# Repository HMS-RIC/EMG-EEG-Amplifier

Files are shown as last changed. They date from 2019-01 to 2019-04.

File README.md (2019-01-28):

# EMG/EEG-Amplifier
3 Channel instrumentation amplifier circuit using AD8221. 

**EMG:** 1 channel, fully differential. 3.2 Hz highpass and 100x gain.   
**EEG:** 2 channels use a common reference. 1.1 Hz highpass and 100x gain.  

Gain is set using a single 499 Ohm resistor per channel. 
Input bandwidth is set by RC network.

Black wire: GND  
Red wire: +5V  
White wire: -5V  
Blue wires (3): Outputs  

.asc file can be opened with LTspice to run the circuit simulation and plot frequency response and transient analysis

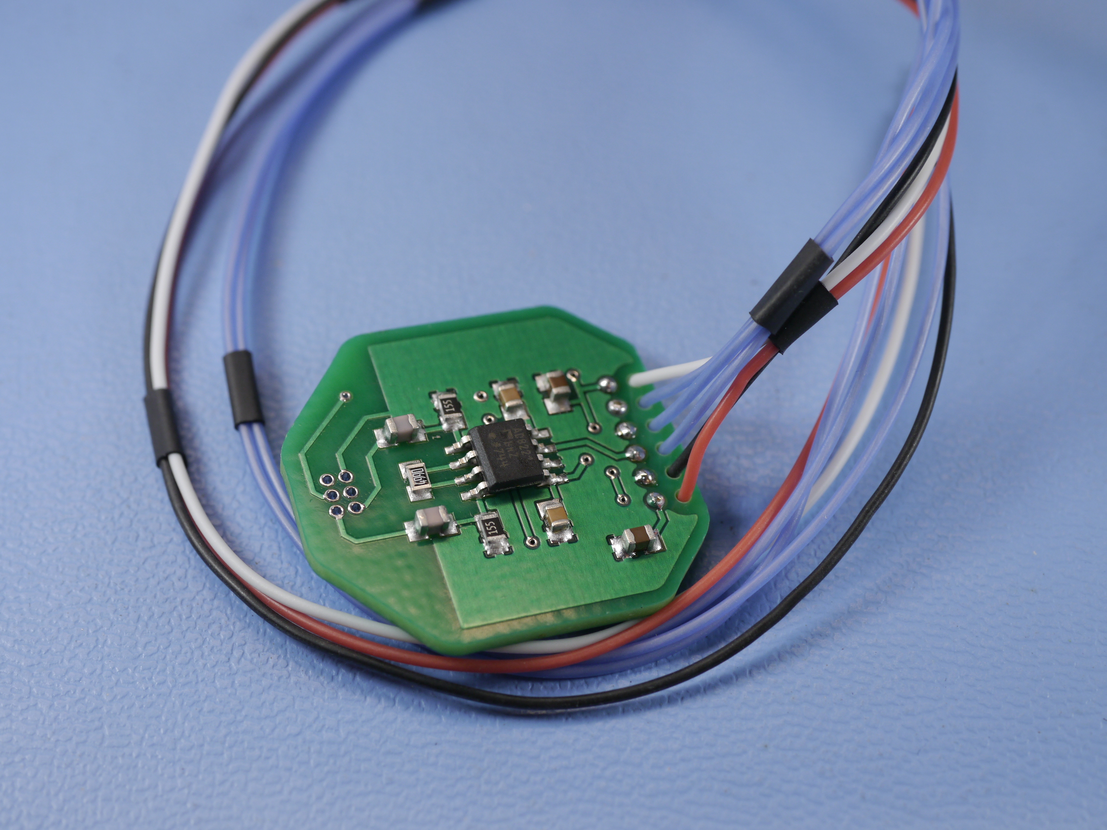
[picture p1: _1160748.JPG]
EMG/EEG Amplifier board


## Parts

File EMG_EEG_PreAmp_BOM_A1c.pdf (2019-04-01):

### Head-mounted EMG and EEG Preamplifier

(Alpha 1c, 2018)

Name | Value | Package | Description | Part Number
C1, C2 | .033 uF | 0805 | Input LP filter (diff channel)
C7, C8, C11, C12 | .1 uF | 0805 | Input LP filter (common channels)
C3, C5, C9, C10, C13, C14 | .1 uF | 0805 | Supply bypass caps
C4, C6 | 10 uF | 0805 | Supply bypass caps
RG1, RG2, RG3 | 499 | 0805 | Gain resistor
R1-R6 | 1.5M | 0805 | LP filter resistor
IC1-IC3 | SOIC8 | Instrumentation amplifier | AD8221

### HP Filter

Capacitors should be low leakage e.g. film
EMG: 1.5M and .01 uF (10.6 Hz cutoff) EEG: 1.5M and .22uF (.48 Hz cutoff)

### Version History:

Alpha 1a (Fabbed 2018)
Alpha 1b (Fabbed 2018)
1. Enlarged holes for millmax connector
2. Realized there is an error. IC3 was not connected to V-

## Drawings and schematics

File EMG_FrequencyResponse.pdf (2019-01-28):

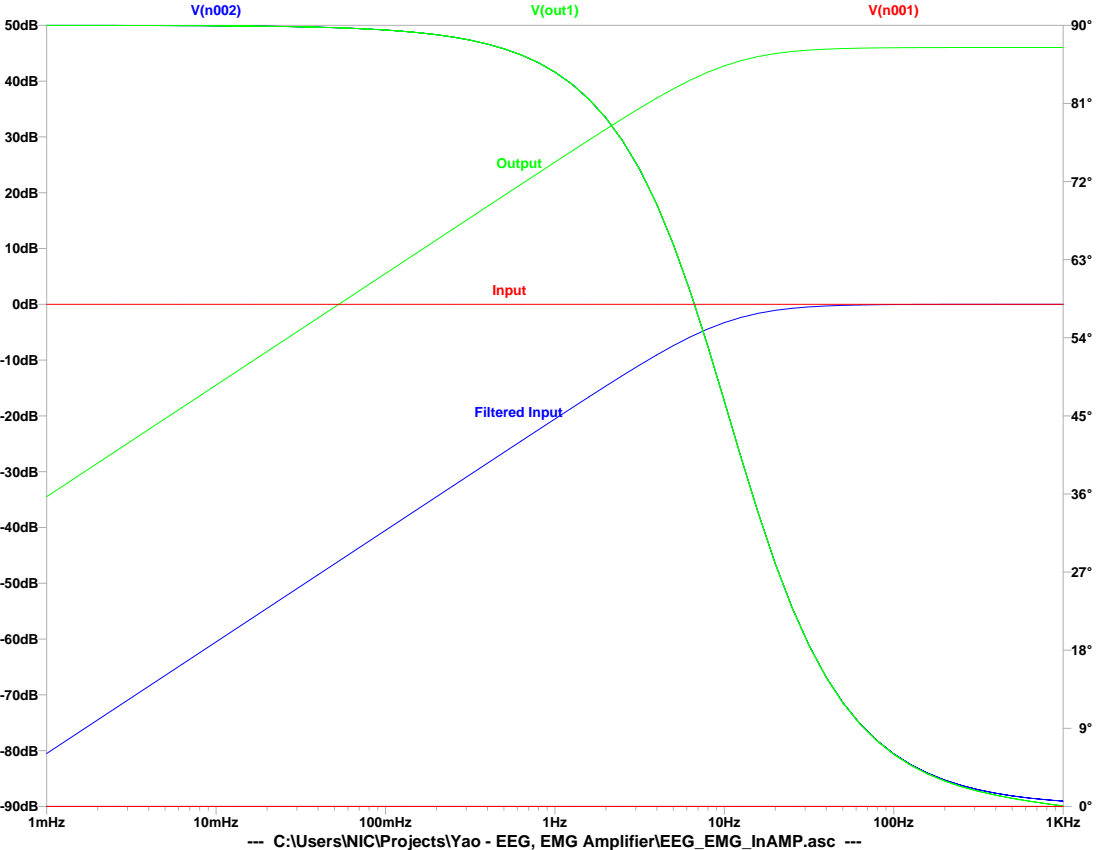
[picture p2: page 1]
1mHz; 10mHz; 100mHz; 1KHz; V(out1); Output; Filtered Input; Input

--- C:\Users\NIC\Projects\Yao - EEG, EMG Amplifier\EEG_EMG_InAMP.asc ---

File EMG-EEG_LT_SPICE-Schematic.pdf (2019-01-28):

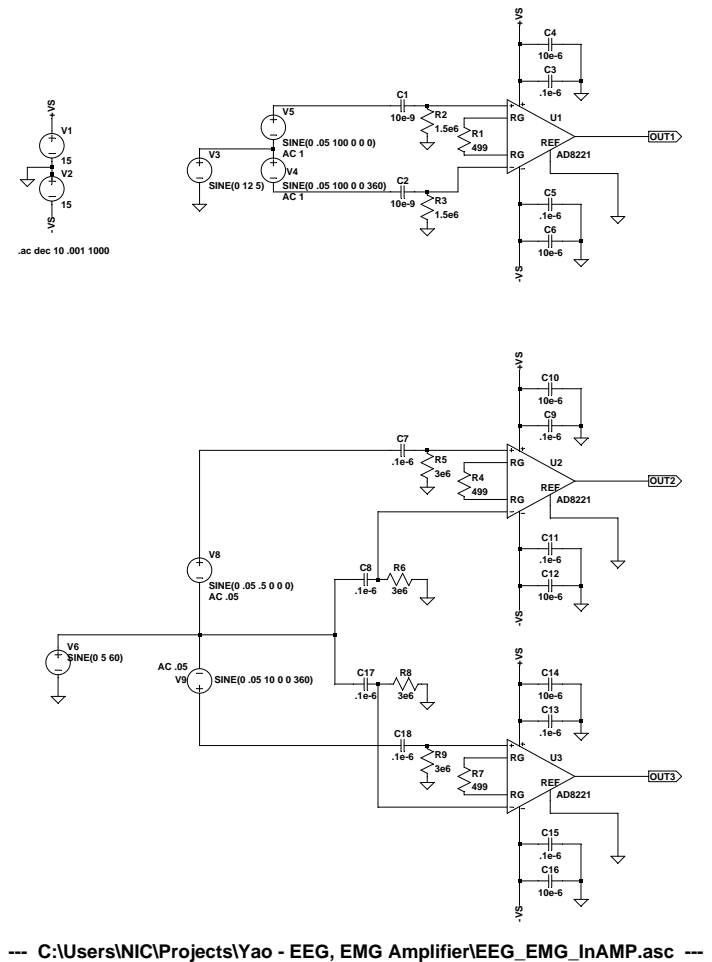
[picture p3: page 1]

--- C:\Users\NIC\Projects\Yao - EEG, EMG Amplifier\EEG_EMG_InAMP.asc ---

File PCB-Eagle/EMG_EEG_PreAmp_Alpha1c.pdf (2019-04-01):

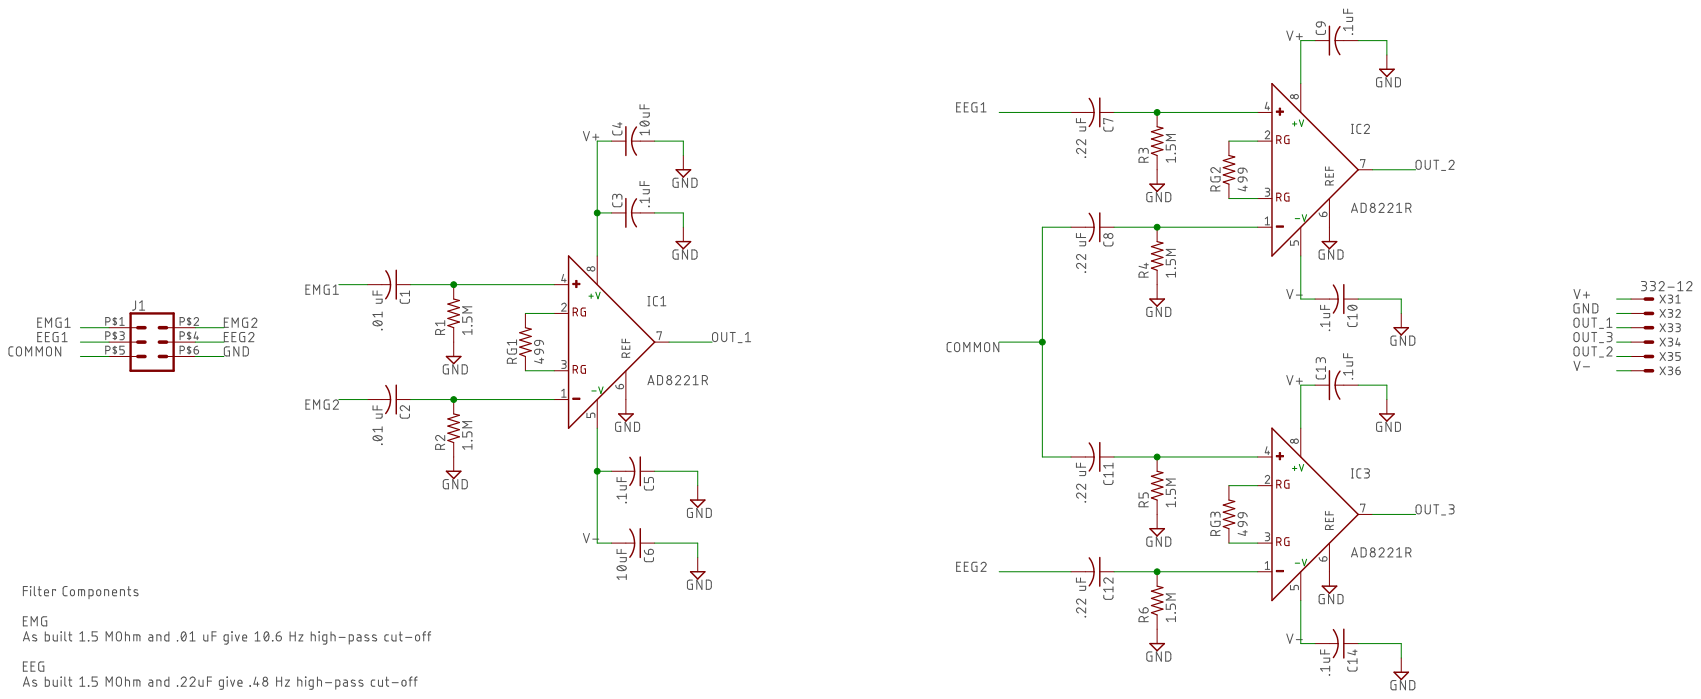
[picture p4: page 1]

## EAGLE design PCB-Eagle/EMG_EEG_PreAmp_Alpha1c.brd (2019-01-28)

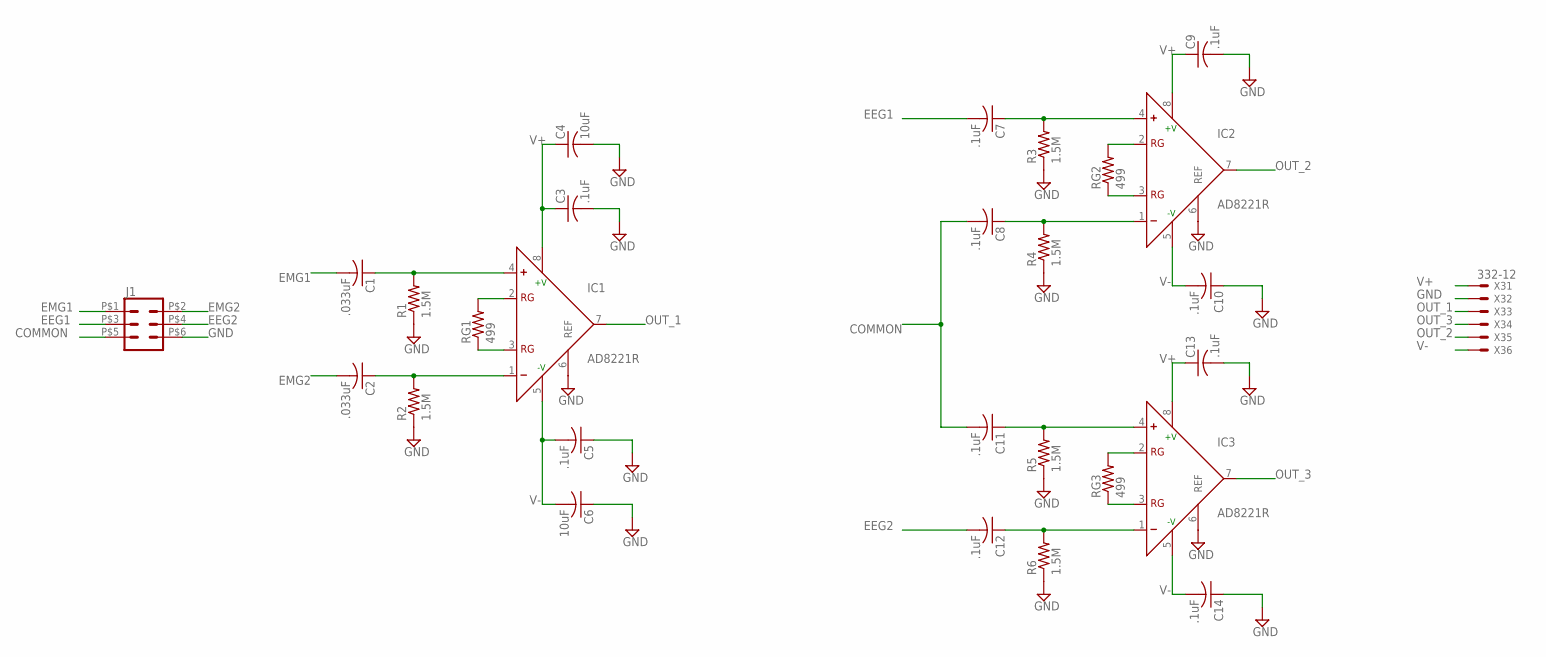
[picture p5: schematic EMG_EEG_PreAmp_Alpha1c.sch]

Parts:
C1, C2: .033uF; C0805K
C3, C5, C7, C8, C9, C10, C11, C12, C13, C14: .1uF; C0805K
C4, C6: 10uF; C0805K
IC1, IC2, IC3: AD8221R; SO8
J1: 2X3MILL-MAX; 2X3_MILL-MAX_853
R1, R2, R3, R4, R5, R6: 1.5M; R0805
RG1, RG2, RG3: 499; R0805
X3: 332-12; 1X6_WITH_STRAIN_RELIEF

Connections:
COMMON: C8.2, C11.2, J1.P$5 (5)
EEG1: C7.2, J1.P$3 (3)
EEG2: C12.2, J1.P$4 (4)
EMG1: C1.2, J1.P$1 (1)
EMG2: C2.2, J1.P$2 (2)
GND: C3.2, C4.2, C5.1, C6.1, C9.2, C10.1, C13.2, C14.1, IC1.6 (REF), IC2.6 (REF), IC3.6 (REF), J1.P$6 (6), R1.1, R2.1, R3.1, R4.1, R5.1, R6.1, X3.2
unnamed: IC1.3 (RG), RG1.1
unnamed: IC1.2 (RG), RG1.2
unnamed: C2.1, IC1.1 (-), R2.2
unnamed: C1.1, IC1.4 (+), R1.2
unnamed: IC2.3 (RG), RG2.1
unnamed: IC2.2 (RG), RG2.2
unnamed: C8.1, IC2.1 (-), R4.2
unnamed: C7.1, IC2.4 (+), R3.2
unnamed: IC3.3 (RG), RG3.1
unnamed: IC3.2 (RG), RG3.2
unnamed: C12.1, IC3.1 (-), R6.2
unnamed: C11.1, IC3.4 (+), R5.2
OUT_1: IC1.7 (OUT), X3.3
OUT_2: IC2.7 (OUT), X3.5
OUT_3: IC3.7 (OUT), X3.4
V+: C3.1, C4.1, C9.1, C13.1, IC1.8 (+V), IC2.8 (+V), IC3.8 (+V), X3.1
V-: C5.2, C6.2, C10.2, C14.2, IC1.5 (-V), IC2.5 (-V), IC3.5 (-V), X3.6

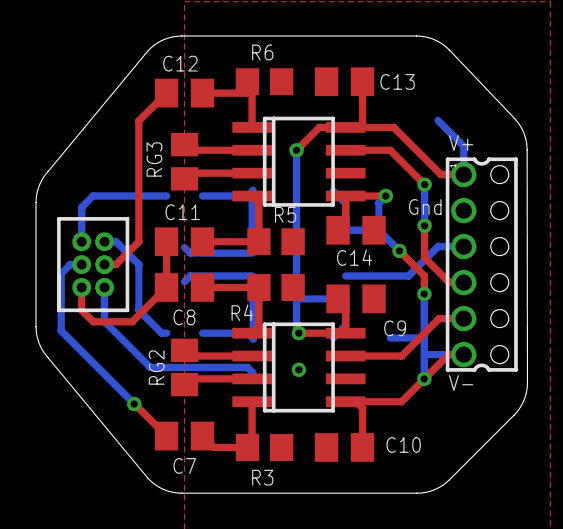
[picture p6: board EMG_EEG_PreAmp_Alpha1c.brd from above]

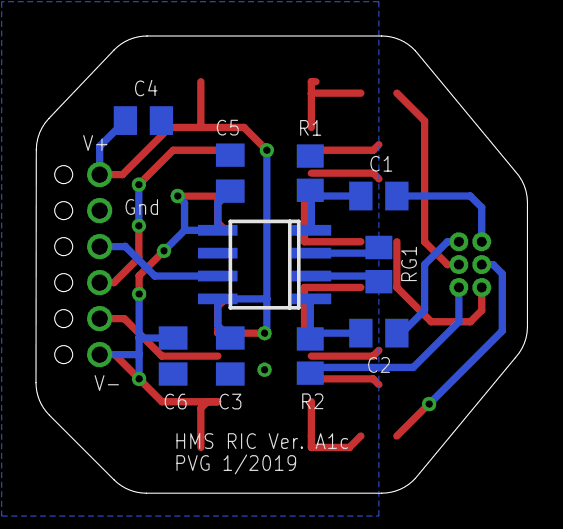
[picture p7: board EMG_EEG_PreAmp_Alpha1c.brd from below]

Board: 2 copper layers, 27.3 x 25.4 mm, 28 parts (10 on the bottom side), 23 nets.
